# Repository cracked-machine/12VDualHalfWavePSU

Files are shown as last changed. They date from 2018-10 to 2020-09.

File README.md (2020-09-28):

## +/-12V output, dual half-wave PSU

Gerbers and BOM files can found in the doc folders.

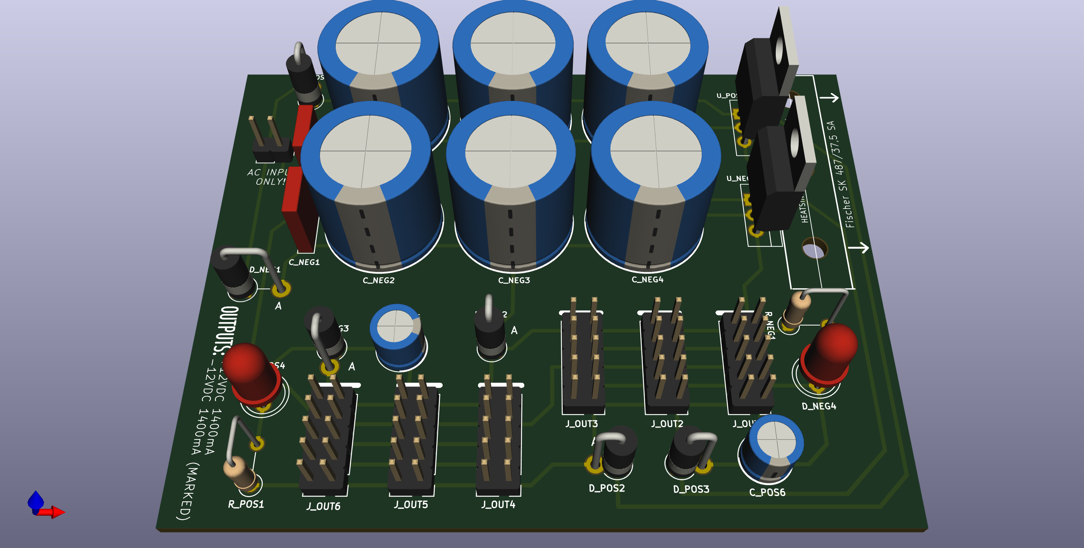
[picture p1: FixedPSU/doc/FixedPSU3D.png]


Now some random instructions and ramblings...

This unit provides a +12V and -12V DC output voltage without a centre-tapped transformer by using a dual half-wave rectifier design. The transformer must be provided by means of an external plug pack.

*It will not work with an AD-DC wall adaptor*. You must use a AC-AC wall adaptor (12VAC @ 1500mA or higher is recommended). These are not so common today but can be found on Ebay (search for "AC/AC adaptor").

A heatsink is also required for the voltage regulators. Fischer Elektronik SK 574/50 is suggested: https://uk.rs-online.com/web/p/heatsinks/7226909/

Since the PSU has only two IDC outputs, there is also an extension board available.
___
This is a common design that can be found online including - but not limited to - Ray "MFOS" Wilson, FrequencyCentral, numerous textbooks..!

The power input - which is the secondary output from the mains transformer - is split two ways. One side is referenced to ground and the other is rectified by the main circuit. The positive going AC waveform is rectified to positive "DC", smoothed by the bulk capacitors and sent to the positive linear regulator. The negative going AC waveform is rectified to negative "DC", smoothed by the bulk capacitors and sent to the negative linear regulator. LEDs show when the positive/negative halves of the circuit are active.



It's a rather noisy circuit. This is a limitation with the half-wave rectifier design: The changing AC waveform and reverse bias of the rectifier causes the transformer output inductance to collapse periodically and abruptly, causing a voltage spike at the transformer output. Perhaps a snubber network across the inputs would help. A full-bridge-rectifier or SMPS design with adequate filtering would be a better but ultimately, more expensive solution.



The linear regulators help to smooth this output ripple, but they have their limits. As such, to prevent excessive output ripple, it's not recommended that the current draw is taken past ~750mA.

To really push this point home, you can see the load regulation limits of the L7912/L7812 linear regulators as they draw more than ~750mA. A deviation higher than 5% is pretty awful.



The 4 bulk capacitors per output are probably also causing havoc with the power correction factor. But let's leave power factor discussions for another day...

---

This circuit is relatively safe (compared to an offline AC/AC PSU) but common sense should be exercised when it comes to electrical safety.

- Avoid touching the capacitor pins when the LEDs are still lit!  They are bulk capacitors and could be storing a significant charge.

Other than your own personal safety, some pointers on preventing the magic smoke:

- Take care not to mix up the pos/neg regulator ICs. L7912 is the negative regulator and L7812 is the positive regulator!

- If you reverse the polarised caps or diodes they may go *pop* when you power the unit up. You have be warned! :D

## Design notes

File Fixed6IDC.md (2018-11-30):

## Fixed dual linear power supply with 6 IDC sockets

- +/-12VDC output
- Ripple current 0.7Vpp @ 1A output (per rail). Appropriately current-rated components must be used. Ripple will decrease with current output.  Heatsink is required!

Fixed dual linear power supply with 6 IDC sockets

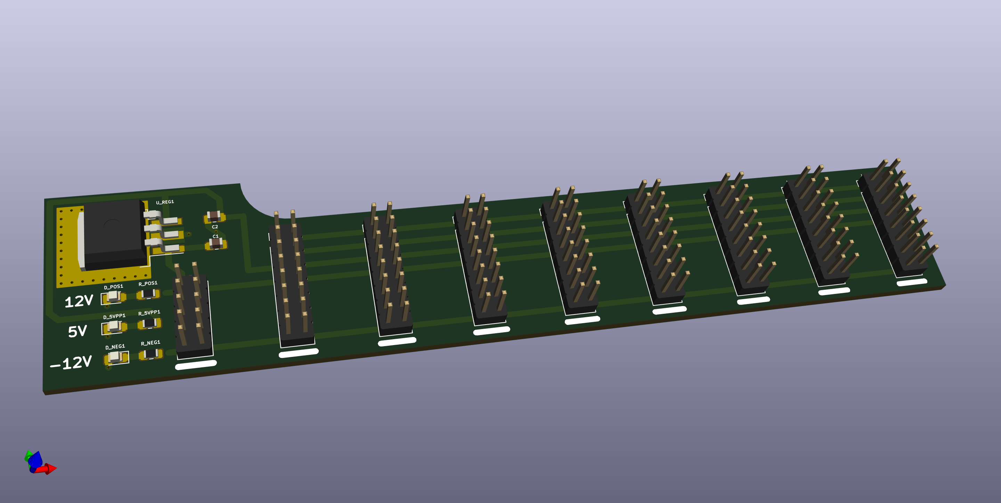
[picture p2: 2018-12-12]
PSUExtensionBoard/doc/PSUExtensionBoard3D.png

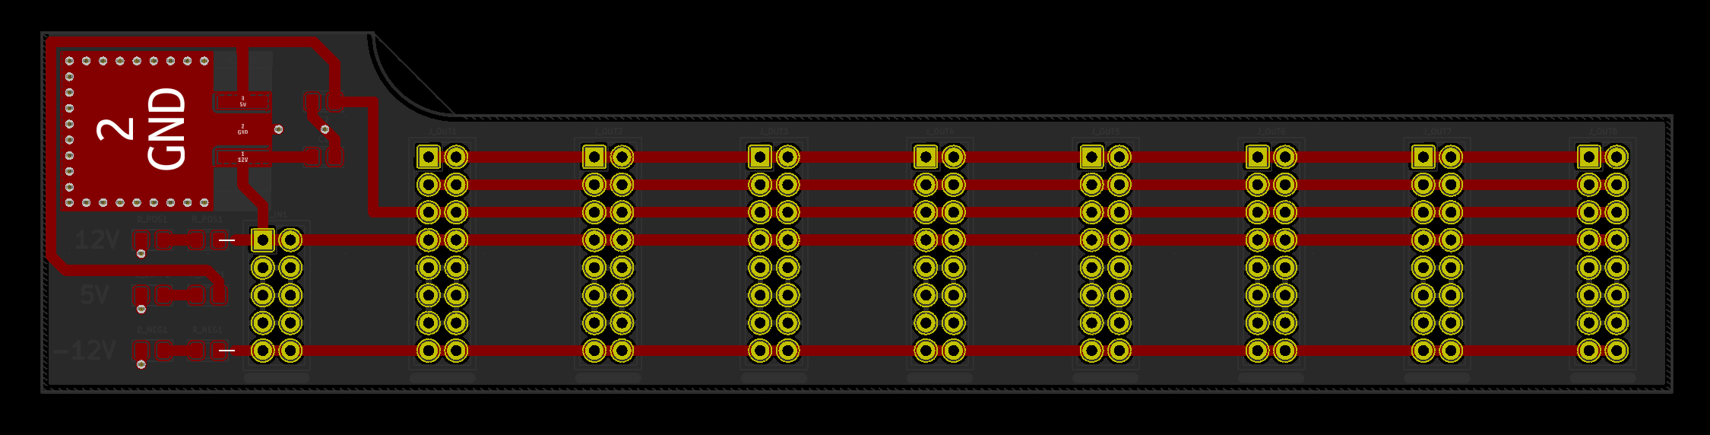
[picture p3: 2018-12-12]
PSUExtensionBoard/doc/Layout.png

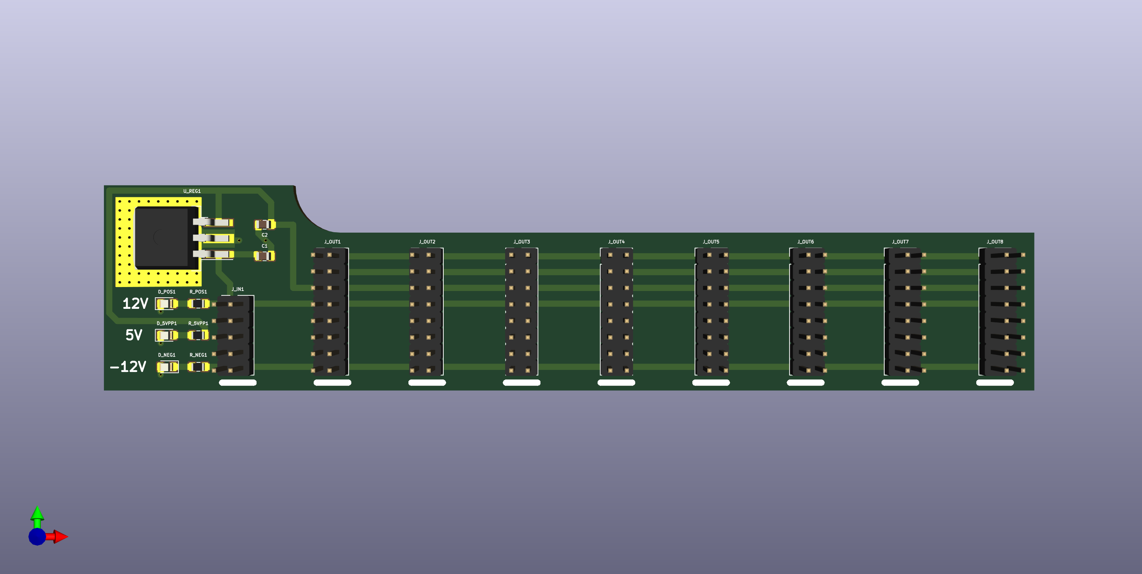
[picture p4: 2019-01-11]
PSUExtensionBoard/doc/PSUExtensionBoard2_3D.png

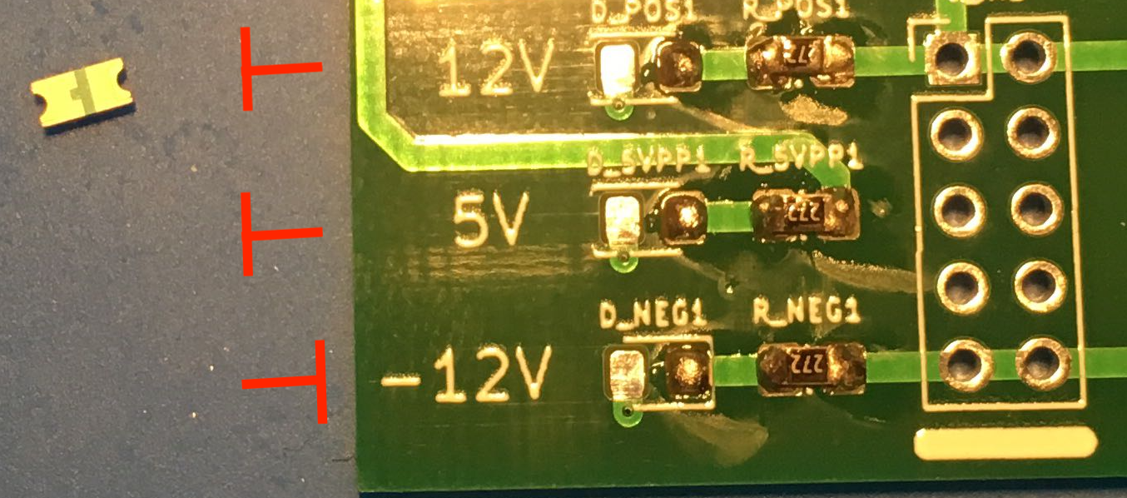
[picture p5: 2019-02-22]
PSUExtensionBoard/doc/LEDposition.png

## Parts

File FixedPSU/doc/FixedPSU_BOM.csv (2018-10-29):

Reference | Value | Footprint | Datasheet
J_PWR1 | Conn_01x02 | Connector_PinHeader_2.54mm:PinHeader_1x02_P2.54mm_Vertical | ~
D_POS1 | 1N4004 | Diode_THT:D_DO-15_P2.54mm_Vertical_AnodeUp | ~
D_NEG1 | 1N4007 | Diode_THT:D_DO-15_P5.08mm_Vertical_AnodeUp | ~
C_POS1 | 100nF | Capacitor_THT:C_Rect_L7.0mm_W2.0mm_P5.00mm | ~
C_NEG1 | 100nF | Capacitor_THT:C_Rect_L7.0mm_W2.0mm_P5.00mm | ~
C_POS2 | 4700uF | Capacitor_THT:CP_Radial_D16.0mm_P7.50mm | ~
C_POS3 | 4700uF | Capacitor_THT:CP_Radial_D16.0mm_P7.50mm | ~
C_POS4 | 4700uF | Capacitor_THT:CP_Radial_D16.0mm_P7.50mm | ~
C_NEG4 | 4700uF | Capacitor_THT:CP_Radial_D16.0mm_P7.50mm | ~
C_NEG3 | 4700uF | Capacitor_THT:CP_Radial_D16.0mm_P7.50mm | ~
C_NEG2 | 4700uF | Capacitor_THT:CP_Radial_D16.0mm_P7.50mm | ~
D_NEG2 | 1N4004 | Diode_THT:D_DO-15_P2.54mm_Vertical_AnodeUp | ~
D_POS2 | 1N4004 | Diode_THT:D_DO-15_P2.54mm_Vertical_AnodeUp | ~
U_POSREG1 | L7812 | Package_TO_SOT_THT:TO-220-3_Vertical | http://www.st.com/content/ccc/resource/technical/document/datasheet/41/4f/b3/b0/12/d4/47/88/CD00000444.pdf/files/CD00000444.pdf/jcr:content/translations/en.CD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
U_NEGREG1 | L7912 | Package_TO_SOT_THT:TO-220-3_Vertical | http://www.st.com/content/ccc/resource/technical/document/datasheet/c9/16/86/41/c7/2b/45/f2/CD00000450.pdf/files/CD00000450.pdf/jcr:content/translations/en.CD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
D_NEG3 | 1N4004 | Diode_THT:D_DO-15_P2.54mm_Vertical_AnodeUp | ~
C_NEG6 | 100uF | Capacitor_THT:CP_Radial_D6.3mm_P2.50mm | ~
C_POS6 | 100uF | Capacitor_THT:CP_Radial_D6.3mm_P2.50mm | ~
D_POS3 | 1N4004 | Diode_THT:D_DO-15_P2.54mm_Vertical_AnodeUp | ~
J_OUT1 | Conn_02x05_Odd_Even | Connector_PinHeader_2.54mm:PinHeader_2x05_P2.54mm_Vertical | ~
J_OUT2 | Conn_02x05_Odd_Even | Connector_PinHeader_2.54mm:PinHeader_2x05_P2.54mm_Vertical | ~
J_OUT3 | Conn_02x05_Odd_Even | Connector_PinHeader_2.54mm:PinHeader_2x05_P2.54mm_Vertical | ~
J_OUT4 | Conn_02x05_Odd_Even | Connector_PinHeader_2.54mm:PinHeader_2x05_P2.54mm_Vertical | ~
J_OUT5 | Conn_02x05_Odd_Even | Connector_PinHeader_2.54mm:PinHeader_2x05_P2.54mm_Vertical | ~
J_OUT6 | Conn_02x05_Odd_Even | Connector_PinHeader_2.54mm:PinHeader_2x05_P2.54mm_Vertical | ~
R_POS1 | 1K | Resistor_THT:R_Axial_DIN0207_L6.3mm_D2.5mm_P5.08mm_Vertical | ~
D_POS4 | LED | LED_THT:LED_D5.0mm | ~
R_NEG1 | 1K | Resistor_THT:R_Axial_DIN0207_L6.3mm_D2.5mm_P5.08mm_Vertical | ~
D_NEG4 | LED | LED_THT:LED_D5.0mm | ~

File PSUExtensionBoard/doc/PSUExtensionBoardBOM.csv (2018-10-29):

Reference | Value | Footprint | Datasheet
J_OUT1 | Conn_02x05_Odd_Even | Connector_PinHeader_2.54mm:PinHeader_2x05_P2.54mm_Vertical | ~
J_OUT2 | Conn_02x05_Odd_Even | Connector_PinHeader_2.54mm:PinHeader_2x05_P2.54mm_Vertical | ~
J_OUT3 | Conn_02x05_Odd_Even | Connector_PinHeader_2.54mm:PinHeader_2x05_P2.54mm_Vertical | ~
J_OUT4 | Conn_02x05_Odd_Even | Connector_PinHeader_2.54mm:PinHeader_2x05_P2.54mm_Vertical | ~
J_OUT5 | Conn_02x05_Odd_Even | Connector_PinHeader_2.54mm:PinHeader_2x05_P2.54mm_Vertical | ~
J_OUT6 | Conn_02x05_Odd_Even | Connector_PinHeader_2.54mm:PinHeader_2x05_P2.54mm_Vertical | ~
D_POS1 | LED | LED_THT:LED_D5.0mm | ~
D_NEG1 | LED | LED_THT:LED_D5.0mm | ~
R_NEG1 | 1K | Resistor_THT:R_Axial_DIN0207_L6.3mm_D2.5mm_P7.62mm_Horizontal | ~
R_POS1 | 1K | Resistor_THT:R_Axial_DIN0207_L6.3mm_D2.5mm_P7.62mm_Horizontal | ~
J_OUT7 | Conn_02x05_Odd_Even | Connector_PinHeader_2.54mm:PinHeader_2x05_P2.54mm_Vertical | ~
J_OUT8 | Conn_02x05_Odd_Even | Connector_PinHeader_2.54mm:PinHeader_2x05_P2.54mm_Vertical | ~
J_OUT9 | Conn_02x05_Odd_Even | Connector_PinHeader_2.54mm:PinHeader_2x05_P2.54mm_Vertical | ~
J_OUT10 | Conn_02x05_Odd_Even | Connector_PinHeader_2.54mm:PinHeader_2x05_P2.54mm_Vertical | ~

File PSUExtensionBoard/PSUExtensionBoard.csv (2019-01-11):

Reference | Value | Footprint | Datasheet | MouserNo
J_IN1 | Conn_02x05_Odd_Even | Connector_PinHeader_2.54mm:PinHeader_2x05_P2.54mm_Vertical | ~
D_POS1 | LED | LED_SMD:LED_0805_2012Metric_Pad1.15x1.40mm_HandSolder | ~ | 630-HSMS-C150
D_NEG1 | LED | LED_SMD:LED_0805_2012Metric_Pad1.15x1.40mm_HandSolder | ~ | 630-HSMS-C150
R_NEG1 | 2K7 | Resistor_SMD:R_0805_2012Metric_Pad1.15x1.40mm_HandSolder | ~ | 71-CRCW08052K70JNE
R_POS1 | 2K7 | Resistor_SMD:R_0805_2012Metric_Pad1.15x1.40mm_HandSolder | ~ | 71-CRCW08052K70JNE
J_OUT1 | Conn_02x08_Odd_Even | Connector_PinHeader_2.54mm:PinHeader_2x08_P2.54mm_Vertical | ~
J_OUT2 | Conn_02x08_Odd_Even | Connector_PinHeader_2.54mm:PinHeader_2x08_P2.54mm_Vertical | ~
J_OUT3 | Conn_02x08_Odd_Even | Connector_PinHeader_2.54mm:PinHeader_2x08_P2.54mm_Vertical | ~
J_OUT4 | Conn_02x08_Odd_Even | Connector_PinHeader_2.54mm:PinHeader_2x08_P2.54mm_Vertical | ~
J_OUT5 | Conn_02x08_Odd_Even | Connector_PinHeader_2.54mm:PinHeader_2x08_P2.54mm_Vertical | ~
J_OUT6 | Conn_02x08_Odd_Even | Connector_PinHeader_2.54mm:PinHeader_2x08_P2.54mm_Vertical | ~
J_OUT7 | Conn_02x08_Odd_Even | Connector_PinHeader_2.54mm:PinHeader_2x08_P2.54mm_Vertical | ~
J_OUT8 | Conn_02x08_Odd_Even | Connector_PinHeader_2.54mm:PinHeader_2x08_P2.54mm_Vertical | ~
C1 | 220nF | Capacitor_SMD:C_0805_2012Metric_Pad1.15x1.40mm_HandSolder | ~
C2 | 100nF | Capacitor_SMD:C_0805_2012Metric_Pad1.15x1.40mm_HandSolder | ~
U_REG1 | L7805 | Package_TO_SOT_SMD:TO-263-3_TabPin2 | http://www.st.com/content/ccc/resource/technical/document/datasheet/41/4f/b3/b0/12/d4/47/88/CD00000444.pdf/files/CD00000444.pdf/jcr:content/translations/en.CD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 | 511-L7805CD2T-TR
R_5VPP1 | 2K7 | Resistor_SMD:R_0805_2012Metric_Pad1.15x1.40mm_HandSolder | ~ | 71-CRCW08052K70JNE
D_5VPP1 | LED | LED_SMD:LED_0805_2012Metric_Pad1.15x1.40mm_HandSolder | ~ | 630-HSMS-C150

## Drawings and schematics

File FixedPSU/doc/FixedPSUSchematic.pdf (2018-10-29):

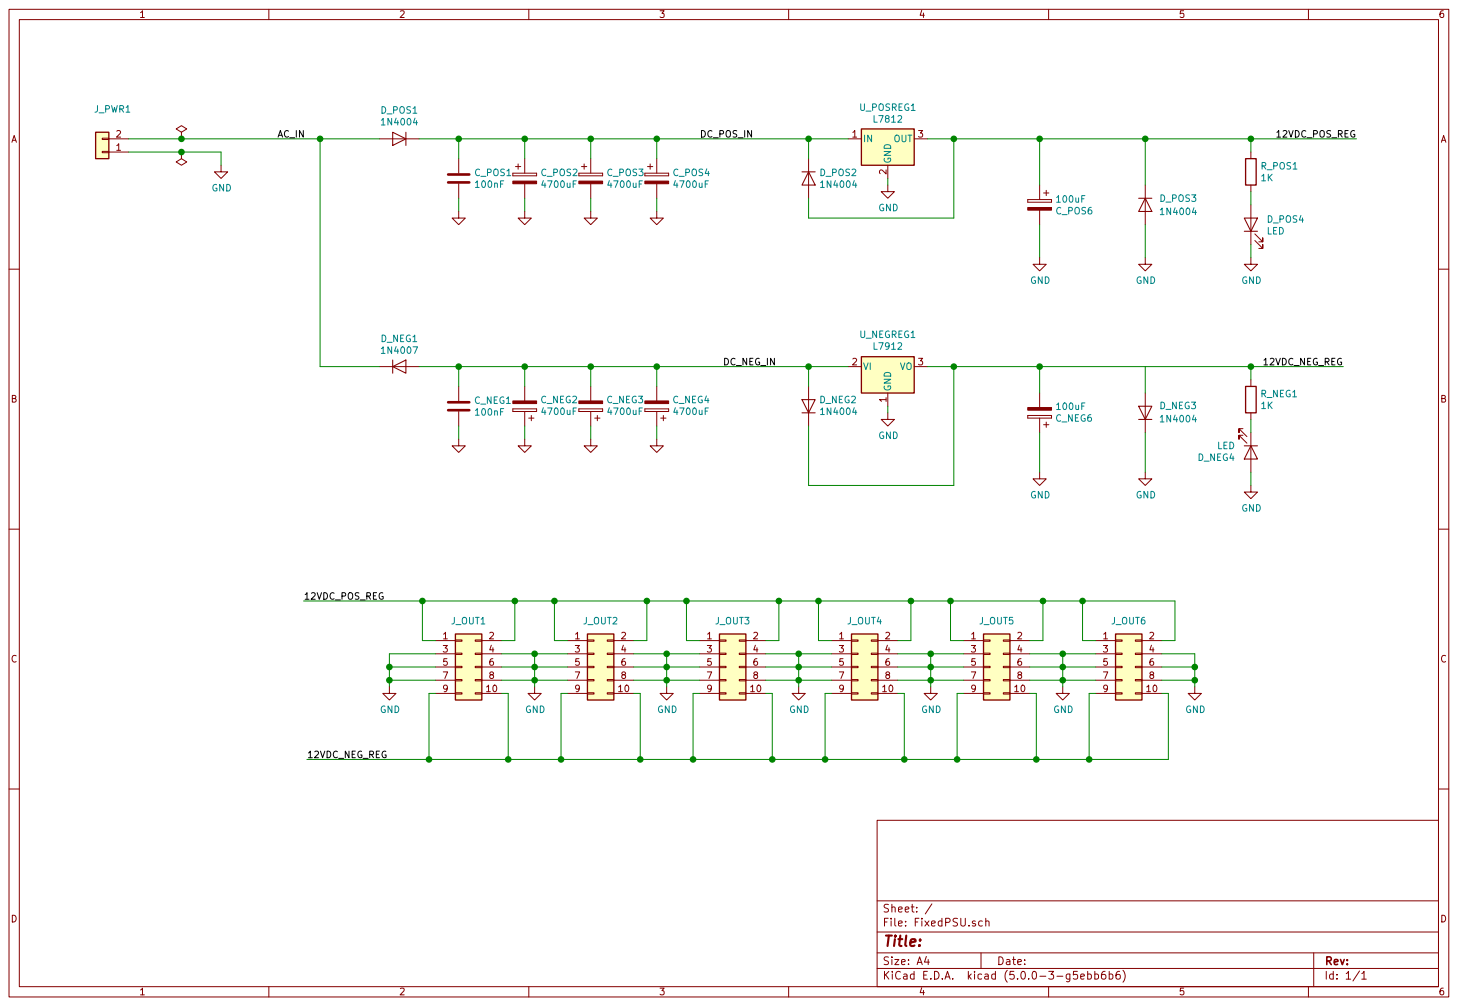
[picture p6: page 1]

Id: 1/1 Title: File: FixedPSU.sch Sheet: /

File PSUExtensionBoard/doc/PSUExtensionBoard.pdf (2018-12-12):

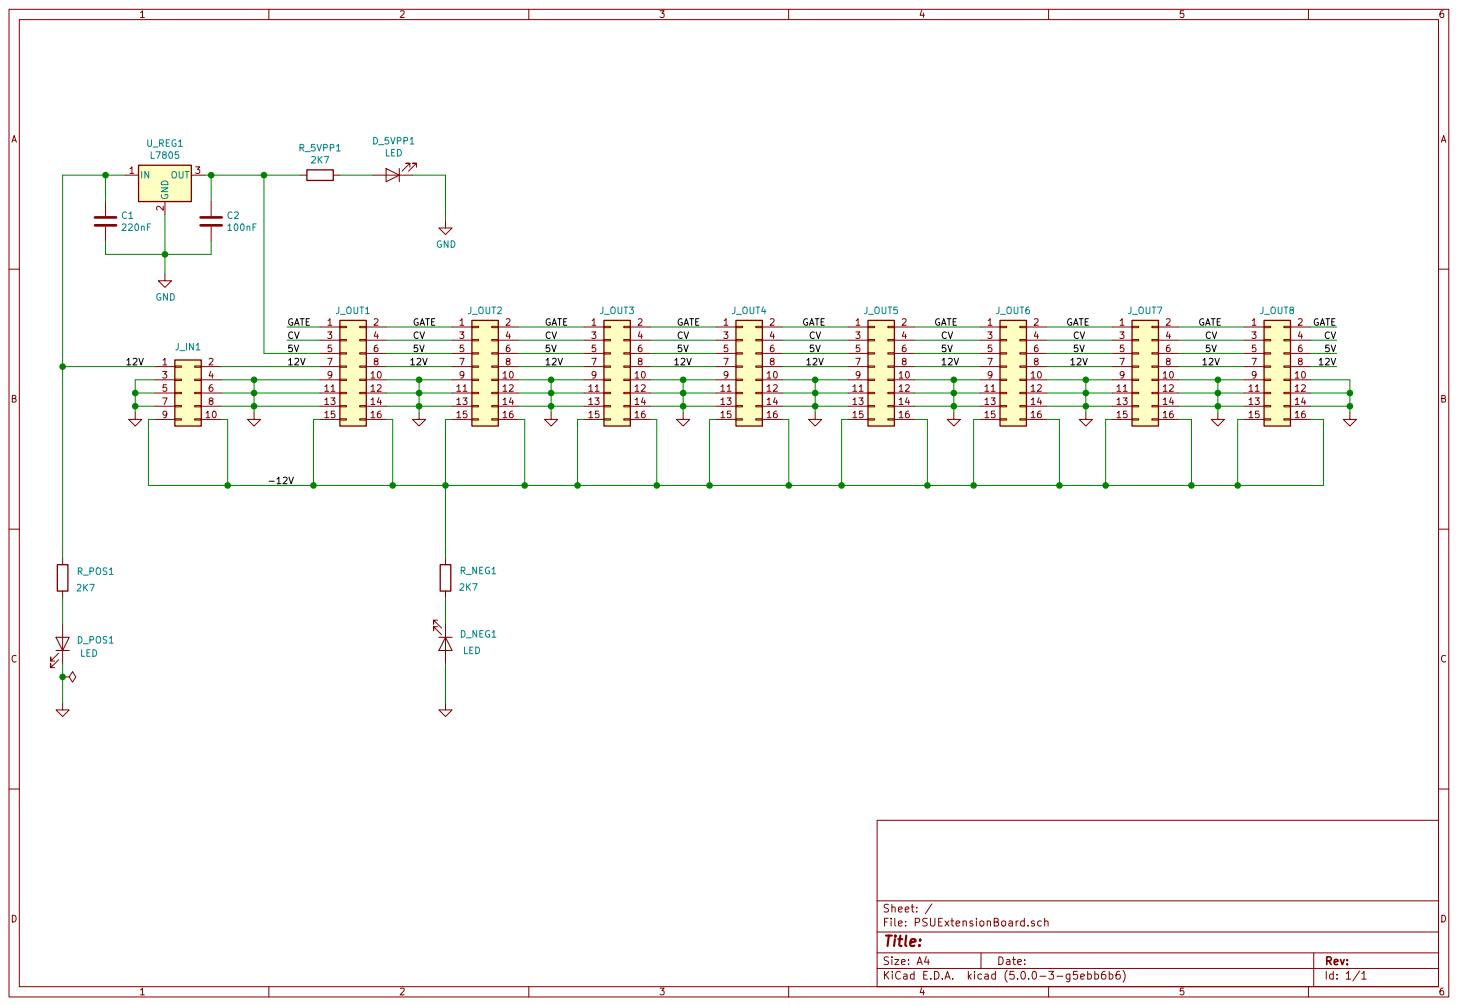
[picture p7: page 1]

3 | 4 3 | | 4 3 | | 4 3 | 4 3 | | 4 3 | | 4
5 | 6 5 | | 6 5 | | 6 5 | 6 5 | | 6 5 | | 6
7 | 8 7 | | 8 7 | | 8 7 | 8 7 | | 8 7 | | 8

3 | 4 9 | | 10 9 | | 10 9 | 10 9 | | 10 9 | | 10 9 | 10 9 | | 10 9
5 | 6 | 11 | | 12 | 11 | 12 | 11 | | 12 | 11 | 12 | 11 | | 12 | 11 | 12 | 11 | 12 | 11 | 12
7 | 8 | 13 | | 14 | 13 | 14 | 13 | | 14 | 13 | 14 | 13 | | 14 | 13 | 14 | 13 | 14 | 13 | 14

Id: 1/1 Title: File: PSUExtensionBoard.sch Sheet: /

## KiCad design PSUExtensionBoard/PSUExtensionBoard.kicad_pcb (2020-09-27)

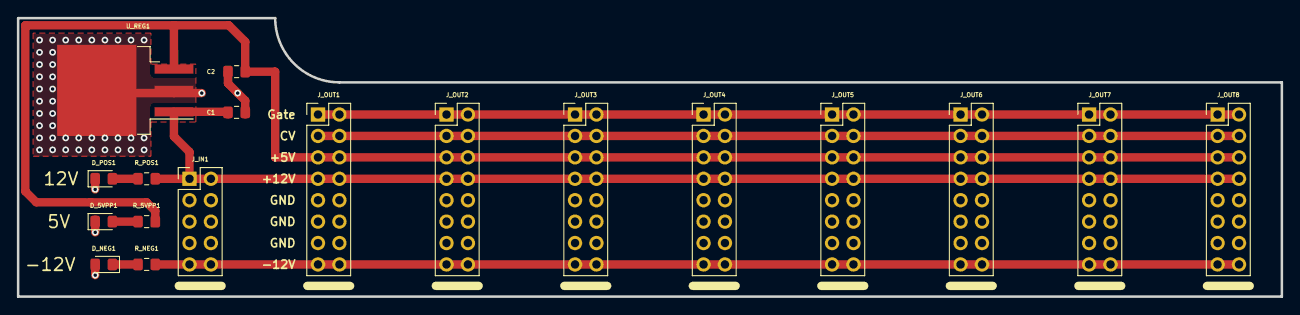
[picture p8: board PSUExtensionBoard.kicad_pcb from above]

Board: 2 copper layers, 149.9 x 33.0 mm, 18 parts (0 on the bottom side), 9 nets.

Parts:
C1: 220nF; C_0805_2012Metric_Pad1.15x1.40mm_HandSolder
C2: 100nF; C_0805_2012Metric_Pad1.15x1.40mm_HandSolder
D_5VPP1: LED; LED_0805_2012Metric_Pad1.15x1.40mm_HandSolder
D_NEG1: LED; LED_0805_2012Metric_Pad1.15x1.40mm_HandSolder
D_POS1: LED; LED_0805_2012Metric_Pad1.15x1.40mm_HandSolder
J_IN1: Conn_02x05_Odd_Even; PinHeader_2x05_P2.54mm_Vertical
J_OUT1, J_OUT2, J_OUT3, J_OUT4, J_OUT5, J_OUT6, J_OUT7, J_OUT8: Conn_02x08_Odd_Even; PinHeader_2x08_P2.54mm_Vertical
R_5VPP1: 2K7; R_0805_2012Metric_Pad1.15x1.40mm_HandSolder
R_NEG1: 2K7; R_0805_2012Metric_Pad1.15x1.40mm_HandSolder
R_POS1: 2K7; R_0805_2012Metric_Pad1.15x1.40mm_HandSolder
U_REG1: L7805; TO-263-3_TabPin2

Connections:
/5V: C2.1, J_OUT1.5, J_OUT1.6, J_OUT2.5, J_OUT2.6, J_OUT3.5, J_OUT3.6, J_OUT4.5, J_OUT4.6, J_OUT5.5, J_OUT5.6, J_OUT6.5, J_OUT6.6, J_OUT7.5, J_OUT7.6, J_OUT8.5, J_OUT8.6, R_5VPP1.2, U_REG1.3
/12V: C1.1, J_IN1.1, J_IN1.2, J_OUT1.7, J_OUT1.8, J_OUT2.7, J_OUT2.8, J_OUT3.7, J_OUT3.8, J_OUT4.7, J_OUT4.8, J_OUT5.7, J_OUT5.8, J_OUT6.7, J_OUT6.8, J_OUT7.7, J_OUT7.8, J_OUT8.7, J_OUT8.8, R_POS1.1, U_REG1.1
/-12V: J_IN1.9, J_IN1.10, J_OUT1.15, J_OUT1.16, J_OUT2.15, J_OUT2.16, J_OUT3.15, J_OUT3.16, J_OUT4.15, J_OUT4.16, J_OUT5.15, J_OUT5.16, J_OUT6.15, J_OUT6.16, J_OUT7.15, J_OUT7.16, J_OUT8.15, J_OUT8.16, R_NEG1.2
/CV: J_OUT1.3, J_OUT1.4, J_OUT2.3, J_OUT2.4, J_OUT3.3, J_OUT3.4, J_OUT4.3, J_OUT4.4, J_OUT5.3, J_OUT5.4, J_OUT6.3, J_OUT6.4, J_OUT7.3, J_OUT7.4, J_OUT8.3, J_OUT8.4
/GATE: J_OUT1.1, J_OUT1.2, J_OUT2.1, J_OUT2.2, J_OUT3.1, J_OUT3.2, J_OUT4.1, J_OUT4.2, J_OUT5.1, J_OUT5.2, J_OUT6.1, J_OUT6.2, J_OUT7.1, J_OUT7.2, J_OUT8.1, J_OUT8.2
GND: C1.2, C2.2, D_5VPP1.1, D_NEG1.2, D_POS1.1, J_IN1.3, J_IN1.4, J_IN1.5, J_IN1.6, J_IN1.7, J_IN1.8, J_OUT1.9, J_OUT1.10, J_OUT1.11, J_OUT1.12, J_OUT1.13, J_OUT1.14, J_OUT2.9, J_OUT2.10, J_OUT2.11, J_OUT2.12, J_OUT2.13, J_OUT2.14, J_OUT3.9, J_OUT3.10, J_OUT3.11, J_OUT3.12, J_OUT3.13, J_OUT3.14, J_OUT4.9, J_OUT4.10, J_OUT4.11, J_OUT4.12, J_OUT4.13, J_OUT4.14, J_OUT5.9, J_OUT5.10, J_OUT5.11, J_OUT5.12, J_OUT5.13, J_OUT5.14, J_OUT6.9, J_OUT6.10, J_OUT6.11, J_OUT6.12, J_OUT6.13, J_OUT6.14, J_OUT7.9, J_OUT7.10, J_OUT7.11, J_OUT7.12, J_OUT7.13, J_OUT7.14, J_OUT8.9, J_OUT8.10, J_OUT8.11, J_OUT8.12, J_OUT8.13, J_OUT8.14, U_REG1.2
unnamed: D_5VPP1.2, R_5VPP1.1
unnamed: D_NEG1.1, R_NEG1.1
unnamed: D_POS1.2, R_POS1.2

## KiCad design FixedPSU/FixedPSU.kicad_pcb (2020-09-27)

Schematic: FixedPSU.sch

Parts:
C_NEG1: 100nF; C_Rect_L7.0mm_W2.0mm_P5.00mm
C_NEG2, C_NEG3, C_NEG4: 4700uF; CP_Radial_D16.0mm_P7.50mm
C_NEG6: 100uF; CP_Radial_D6.3mm_P2.50mm
C_POS1: 100nF; C_Rect_L7.0mm_W2.0mm_P5.00mm
C_POS2, C_POS3, C_POS4: 4700uF; CP_Radial_D16.0mm_P7.50mm
C_POS6: 100uF; CP_Radial_D6.3mm_P2.50mm
D_NEG1: 1N4007; D_DO-15_P5.08mm_Vertical_AnodeUp
D_NEG2, D_NEG3: 1N4004; D_DO-15_P2.54mm_Vertical_AnodeUp
D_NEG4: LED; LED_D5.0mm
D_POS1, D_POS2, D_POS3: 1N4004; D_DO-15_P2.54mm_Vertical_AnodeUp
D_POS4: LED; LED_D5.0mm
J_OUT1, J_OUT2, J_OUT3, J_OUT4, J_OUT5, J_OUT6: Conn_02x05_Odd_Even; PinHeader_2x05_P2.54mm_Vertical
J_PWR1: Conn_01x02; PinHeader_1x02_P2.54mm_Vertical
R_NEG1: 1K; R_Axial_DIN0207_L6.3mm_D2.5mm_P5.08mm_Vertical
R_POS1: 1K; R_Axial_DIN0207_L6.3mm_D2.5mm_P5.08mm_Vertical
U_NEGREG1: L7912; TO-220-3_Vertical
U_POSREG1: L7812; TO-220-3_Vertical

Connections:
/12VDC_NEG_REG: C_NEG6.2, D_NEG2.1, D_NEG3.2, J_OUT1.9, J_OUT1.10, J_OUT2.9, J_OUT2.10, J_OUT3.9, J_OUT3.10, J_OUT4.9, J_OUT4.10, J_OUT5.9, J_OUT5.10, J_OUT6.9, J_OUT6.10, R_NEG1.1, U_NEGREG1.3 (VO)
/12VDC_POS_REG: C_POS6.1, D_POS2.2, D_POS3.1, J_OUT1.1, J_OUT1.2, J_OUT2.1, J_OUT2.2, J_OUT3.1, J_OUT3.2, J_OUT4.1, J_OUT4.2, J_OUT5.1, J_OUT5.2, J_OUT6.1, J_OUT6.2, R_POS1.1, U_POSREG1.3 (OUT)
/AC_IN: D_NEG1.1, D_POS1.2, J_PWR1.2
/DC_NEG_IN: C_NEG1.1, C_NEG2.2, C_NEG3.2, C_NEG4.2, D_NEG1.2, D_NEG2.2, U_NEGREG1.2 (VI)
/DC_POS_IN: C_POS1.1, C_POS2.1, C_POS3.1, C_POS4.1, D_POS1.1, D_POS2.1, U_POSREG1.1 (IN)
GND: C_NEG1.2, C_NEG2.1, C_NEG3.1, C_NEG4.1, C_NEG6.1, C_POS1.2, C_POS2.2, C_POS3.2, C_POS4.2, C_POS6.2, D_NEG3.1, D_NEG4.2, D_POS3.2, D_POS4.1, J_OUT1.3, J_OUT1.4, J_OUT1.5, J_OUT1.6, J_OUT1.7, J_OUT1.8, J_OUT2.3, J_OUT2.4, J_OUT2.5, J_OUT2.6, J_OUT2.7, J_OUT2.8, J_OUT3.3, J_OUT3.4, J_OUT3.5, J_OUT3.6, J_OUT3.7, J_OUT3.8, J_OUT4.3, J_OUT4.4, J_OUT4.5, J_OUT4.6, J_OUT4.7, J_OUT4.8, J_OUT5.3, J_OUT5.4, J_OUT5.5, J_OUT5.6, J_OUT5.7, J_OUT5.8, J_OUT6.3, J_OUT6.4, J_OUT6.5, J_OUT6.6, J_OUT6.7, J_OUT6.8, J_PWR1.1, U_NEGREG1.1 (GND), U_POSREG1.2 (GND)
unnamed: D_NEG4.1, R_NEG1.2
unnamed: D_POS4.2, R_POS1.2

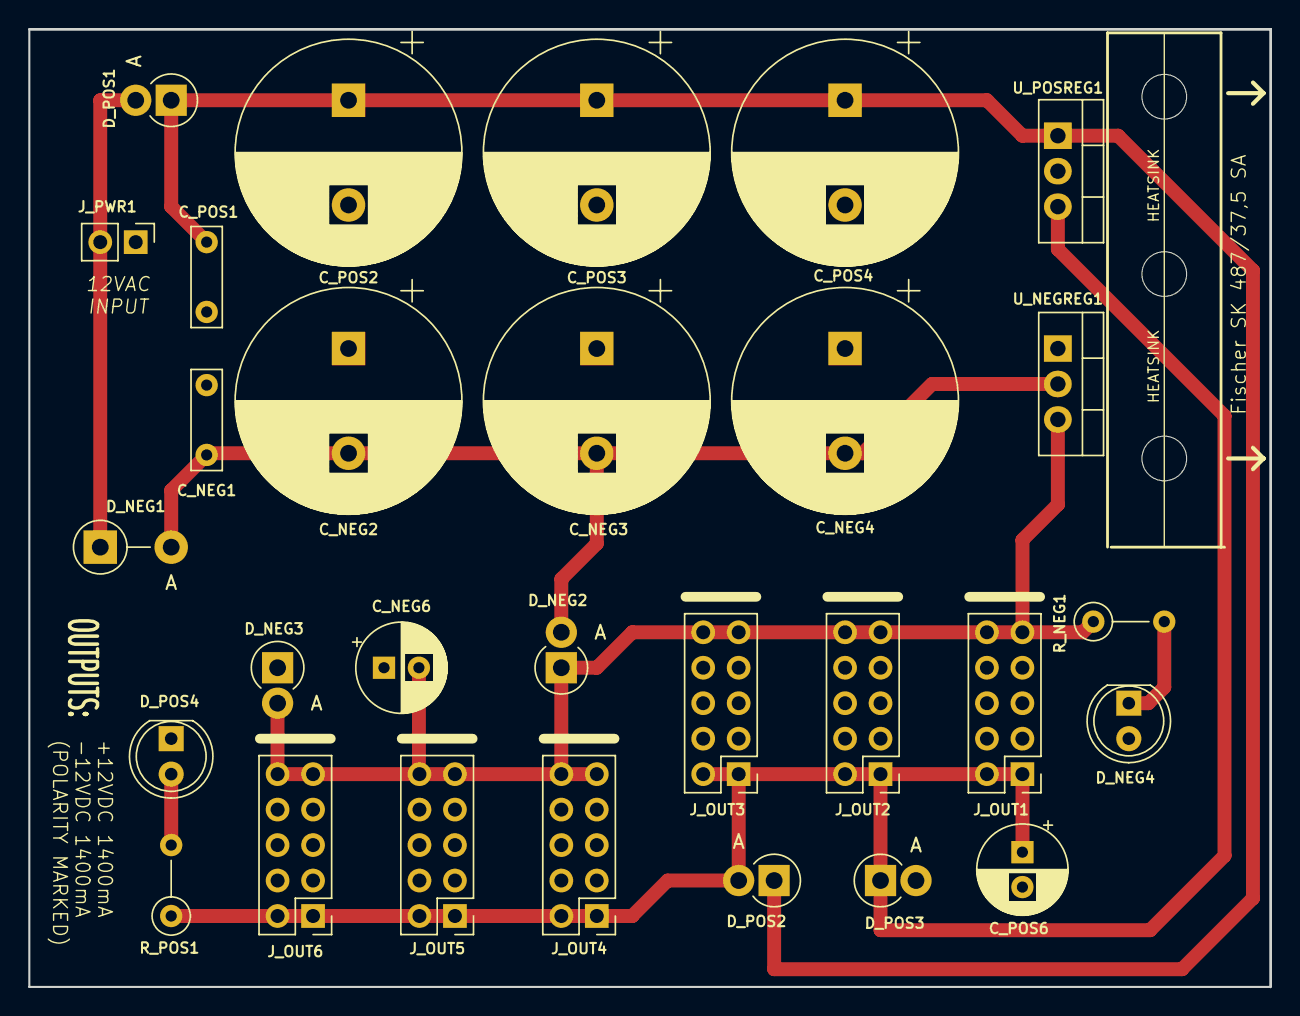
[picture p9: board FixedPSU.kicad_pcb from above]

Board: 2 copper layers, 88.9 x 68.6 mm, 29 parts (0 on the bottom side), 8 nets.

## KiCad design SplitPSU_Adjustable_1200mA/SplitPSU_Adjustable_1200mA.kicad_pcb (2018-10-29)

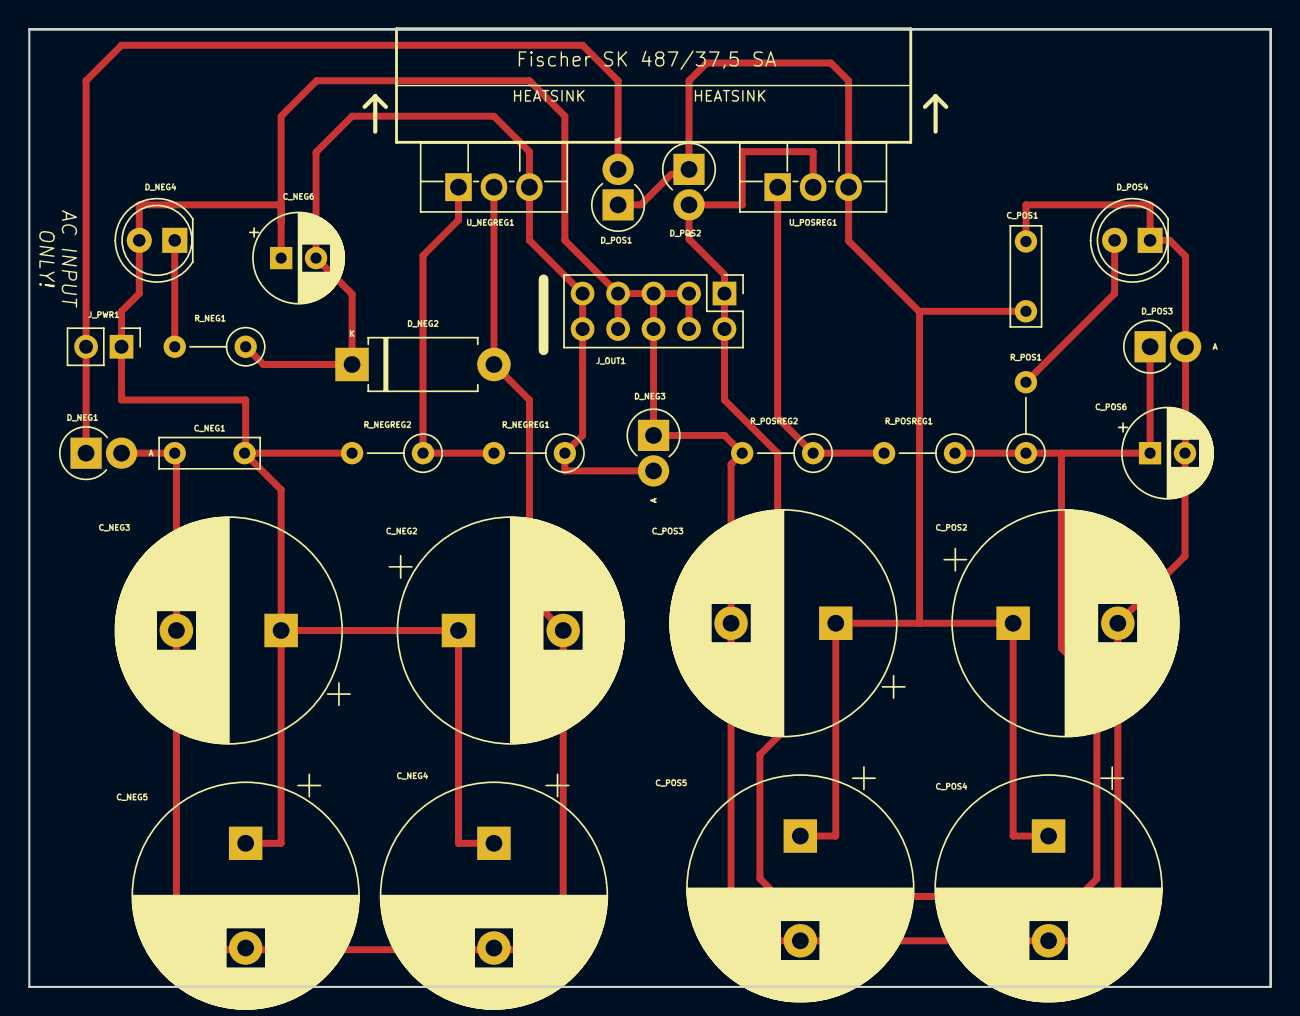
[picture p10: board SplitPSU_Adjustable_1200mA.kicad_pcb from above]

Board: 2 copper layers, 88.9 x 68.6 mm, 30 parts (0 on the bottom side), 10 nets.

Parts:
C_NEG1: 100nF; C_Rect_L7.0mm_W2.0mm_P5.00mm
C_NEG2, C_NEG3, C_NEG4, C_NEG5: 4700uF; CP_Radial_D16.0mm_P7.50mm
C_NEG6: 100uF; CP_Radial_D6.3mm_P2.50mm
C_POS1: 100nF; C_Rect_L7.0mm_W2.0mm_P5.00mm
C_POS2, C_POS3, C_POS4, C_POS5: 4700uF; CP_Radial_D16.0mm_P7.50mm
C_POS6: 100uF; CP_Radial_D6.3mm_P2.50mm
D_NEG1: 1N4007; D_DO-15_P2.54mm_Vertical_AnodeUp
D_NEG2: 1N4004; D_DO-15_P10.16mm_Horizontal
D_NEG3: 1N4004; D_DO-15_P2.54mm_Vertical_AnodeUp
D_NEG4: LED; LED_D5.0mm
D_POS1, D_POS2, D_POS3: 1N4004; D_DO-15_P2.54mm_Vertical_AnodeUp
D_POS4: LED; LED_D5.0mm
J_OUT1: Conn_02x05_Odd_Even; PinHeader_2x05_P2.54mm_Vertical
J_PWR1: Conn_01x02; PinHeader_1x02_P2.54mm_Vertical
R_NEG1: 1K; R_Axial_DIN0207_L6.3mm_D2.5mm_P5.08mm_Vertical
R_NEGREG1: 120R; R_Axial_DIN0207_L6.3mm_D2.5mm_P5.08mm_Vertical
R_NEGREG2: 390R; R_Axial_DIN0207_L6.3mm_D2.5mm_P5.08mm_Vertical
R_POS1: 1K; R_Axial_DIN0207_L6.3mm_D2.5mm_P5.08mm_Vertical
R_POSREG1: 120R; R_Axial_DIN0207_L6.3mm_D2.5mm_P5.08mm_Vertical
R_POSREG2: 390R; R_Axial_DIN0207_L6.3mm_D2.5mm_P5.08mm_Vertical
U_NEGREG1: LM337_TO220; TO-220F-3_Vertical
U_POSREG1: LM317_3PinPackage; TO-220F-3_Vertical

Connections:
/12VDC_NEG_REG: C_NEG6.2, D_NEG2.1, D_NEG3.2, J_OUT1.9, J_OUT1.10, R_NEG1.1, R_NEGREG1.1, U_NEGREG1.3
/12VDC_POS_REG: C_POS6.1, D_POS2.2, D_POS3.1, J_OUT1.1, J_OUT1.2, R_POS1.1, R_POSREG1.1, U_POSREG1.2
/AC_IN: D_NEG1.1, D_POS1.2, J_PWR1.2
/DC_NEG_IN: C_NEG1.1, C_NEG2.2, C_NEG3.2, C_NEG4.2, C_NEG5.2, D_NEG1.2, D_NEG2.2, U_NEGREG1.2
/DC_POS_IN: C_POS1.1, C_POS2.1, C_POS3.1, C_POS4.1, C_POS5.1, D_POS1.1, D_POS2.1, U_POSREG1.3
GND: C_NEG1.2, C_NEG2.1, C_NEG3.1, C_NEG4.1, C_NEG5.1, C_NEG6.1, C_POS1.2, C_POS2.2, C_POS3.2, C_POS4.2, C_POS5.2, C_POS6.2, D_NEG3.1, D_NEG4.2, D_POS3.2, D_POS4.1, J_OUT1.3, J_OUT1.4, J_OUT1.5, J_OUT1.6, J_OUT1.7, J_OUT1.8, J_PWR1.1, R_NEGREG2.2, R_POSREG2.2
unnamed: D_NEG4.1, R_NEG1.2
unnamed: D_POS4.2, R_POS1.2
unnamed: R_NEGREG1.2, R_NEGREG2.1, U_NEGREG1.1
unnamed: R_POSREG1.2, R_POSREG2.1, U_POSREG1.1

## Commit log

2018-10-29 Schematic and board layouts added
    [Split12V_1200mA_PowerSupply.kicad_pcb, Split12V_1200mA_PowerSupply.sch, SplitPSU_Adjustable_1200mA.kicad_pcb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]
2018-10-29 Docs created
    [AdjustablePSU.kicad_pcb, AdjustablePSU.sch, AdjustablePSUBOM.csv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]
2018-11-22 Changed Adjustable design to use ground plane
    [AdjustablePSU.kicad_pcb, AdjustablePSU.sch]
2018-11-22 Updated silkscreen
    [AdjustablePSU.kicad_pcb, AdjustablePSU.sch]
2018-11-24 Finished RevA board
    [AdjustablePSU-B.Cu.gbr, AdjustablePSU-B.Mask.gbr, AdjustablePSU-B.Paste.gbr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]
2018-11-30 Added new assembled photo for AdjustablePSU
2018-12-12 Changed Ext Board to add 5V, CV, Gate
    [PSUExtensionBoard.kicad_pcb, PSUExtensionBoard.sch]
2019-01-11 Created SMT version of AdjustablePSU, RevB
    [AdjustablePSU-B.Cu.gbr, AdjustablePSU-B.Mask.gbr, AdjustablePSU-B.Paste.gbr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]
2019-02-06 RevC update
    [AdjustablePSU-B.Cu.gbr, AdjustablePSU-B.Mask.gbr, AdjustablePSU-B.Paste.gbr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]
2019-02-09 Added hybrid THT/SMT RevD
    [AdjustablePSU.kicad_pcb, AdjustablePSU.sch]
2019-05-07 locked NPTH
    [AdjustablePSU.kicad_pcb]
2019-05-07 Centered On Grid
    [AdjustablePSU.sch]
2019-05-07 Adjustable PSU RevD
    - Layout Redesign 97mm x 50mm
    - Removed 4/8 Large Electrolytic Caps
    - Added Power Resistor pair to filter ripple.
    - Added docs: Layer SVG, Schema SVG/PDF, PNG Renders, STEP 3D model
    [AdjustablePSU.kicad_pcb, AdjustablePSU.sch, AdjustablePSU.step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]
2020-09-27 added gerbers files for fixed psu and extension board
    [FixedPSU-B_Cu.gbr, FixedPSU-B_Mask.gbr, FixedPSU-B_Paste.gbr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]
2020-09-28 updated readme
    - added characteristic graph plot results
    [AdjustablePSU-B_Cu.gbr, AdjustablePSU-B_Mask.gbr, AdjustablePSU-B_Paste.gbr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]
